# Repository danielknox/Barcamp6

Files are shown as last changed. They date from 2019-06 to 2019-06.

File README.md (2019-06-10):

# Barcamp6
Puzzle and Badges for Barcamp 6

Barcamp 6's theme was loosely based around the film The Fifth Element. Throughout the day a puzzle game played out for the 50+ attendees. In this repo are the files that made up the game. 

The badges, given to each attendee, are used to provide a clue to each tribe to locate their artefact and are used as part of the end sequence animation. They also fade their lights in/out approximately every 8 seconds (which looks quite cool when people are speaking/sitting in groups). 

The pcbs and puzzles took about two months to develop and produce. 

Special thanks to: 
Keith Greenhow (helped develop a number of the puzzles -- like the fourtime pad
Martin Falkner (for helping to assemble 40+ pcbs!)

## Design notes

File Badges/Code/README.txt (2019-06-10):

Needs the FastLED and IRLremote libraries. This can be compiled for attiny85 (production) or uno/leonardo (for debugging). 

I use https://raw.githubusercontent.com/damellis/attiny/ide-1.6.x-boards-manager/package_damellis_attiny_index.json. to compile for the ATtiny85 from the Arduino IDE:
- 8MHz internal clock.

HOWEVER! You need to modify the pins_arduino.h (appData/local/arduino15/packages/attiny/hardware/avr/1.0.2/variants/tiny8) to have the digitalPinToInterrupt macro.

Add this:
'#define digitalPinToInterrupt(p)  ((p) == 2 ? 0 : NOT_AN_INTERRUPT);

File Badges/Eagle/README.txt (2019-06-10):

Gerbers should contain the ready to go files, schematics contains the Eagle board files.

Fabrication:
I used SEEEDSTUDIO for board fabrication.

For production, Barcamp stencil was used with bi-directional engraving on laser cutter using OHP asertate. Laser outline was used to create a simple nested jig (0.1mm offset).
Use ducktape to secure acertate to jig and paste away!

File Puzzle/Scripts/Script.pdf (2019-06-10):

# Script

# Introduction

In the beginning there were four great tribes and they forged wondrous, magical artifacts: one of fire, one of water, one of earth and one of air.

The four seeked to expand their power and for centuries there was conflict.
Any peace was short lived.

As time moved on, the four became tired of war and an unsteady calm befell the land. Trade slowly grew and the four vied for power in other ways.

Fearful of what would happen if any nation was able to wield more than one artifact, they were hidden away and the locations of the artifacts (and how to use them) were gifted to a select few. But as with all things, this knowledge was slowly lost.

The artifacts are now little more than legend, but a great calamity is fortelled. Interest in the artifacts has grown and the other tribes covet their power once more. You have been tasked with uncovering the clues of our ancestors, recovering the artifacts and to wield them to stop our nation’s demise.

Attendees of Barcamp 6, you have until the end of the day to recover the lost artifact and the instructions on how to use them. At the end of the day we will gather together to perform the activation ritual to discover your fates.

# Altar Ceremony

1. “Can the four Stone Bearers come forth.”
2. Get upto four volunteers to bring their claimed stones to the front.
3. Repeat the following steps for each Stone, X, present:
a. Connect to the stone X’s BLE interface.
b. “Bearer of the X Stone; place the X Stone on the Altar”
c. Wait for the stone to be placed on the altar in its correct position.
d. “Please awaken the X Stone”
e. Once they reenact the relevant part of the Fifth Element end sequence
i. The wind blows
ii. | The fire burns
iii. | The rain falls
iv. | The ground stays
f. Set the X stone to mode 0x01.
g. “Now enter your activation sequence”
h. Wait for them to finish
i. Take note of Stone X’s final rotary position into victory calculator
j. “Please return from the altar”
4. After all present stones have been awakened and activated
5. Set the stones modes to the final states shown on the calculator (to show who betrayed whom).
6. Play badge outro shown on calculator.
7. Read out epilogues shown on calculator. (see below for narrative)

# Epilogues

## Failure cases

### For factions that failed to recover/activate their artifact

With the rise of the great calamity, your defenses fall; and your people scatter. You have died of dysentery.

### For factions that recover one artifact and selfishly activate

You wield the power of the artifact and your nation is invigorated and strengthened. Your people hold their own, but they (too) eventually succumb to the great calamity.

### For factions that claim multiple artifacts

You wield the power of (two/three/all four) artifacts and your nation is invigorated and strengthened beyond all previous measure. Your people fend of the great calamity and hold steadfast. But power lust grows in your capital and in a moment of weakness the great calamity takes the upper hand and strikes you people down.

## Success

You activate the four great artifacts and unite their power. With this unity, the calamity is averted, our leaders commit to working together and you witness the birth of a new age of greatness.

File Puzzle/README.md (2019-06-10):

# Barcamp Puzzles!

Barcamp 6 incorporated a puzzle game which played out throughout the day. Each attendee was assigned to a tribe (they were given an e-badge which flashed a team colour and had a coloured solder mask). The tribes had to recover an artifact of power and the information (scroll) to activate it. The clues available encouraged tribes to work individualistically (e.g. blaze vs terra), but each tribe would ultimately choose if they would activate the artifact for the benefit (?) of their tribe or for the benefit of all. Each tribe had a national newspaper and this was available from the newspaper stand during lunch - the newspaper contained a number of clues and backstory information.

A box (here-on called Pandora's Box) was placed in the main foyer during one of the talks. This box had a number of locks (key + combination). The box required much more working together between the tribes in order to remove all the locks. The box contained the writing "When you come, be prepared to share with barcampers. When you leave, be prepared to share it with the world." and the symbol for unity (each scroll had the symbol on it, as well as the other tribes symbols).

Listed below are the various puzzles that made up Barcamp 6.

## Artifact Locations
Each tribe's artifact was hidden in a different locations across campus. Each tribe's badge had a silkscreened clue on its rear revealing the location: Keynes duckpond (tribe flood),  Synapse-Soleil (tribe blaze), Wind-wall (tribe wind), Darwin's Primordial tree (tribe Terra).

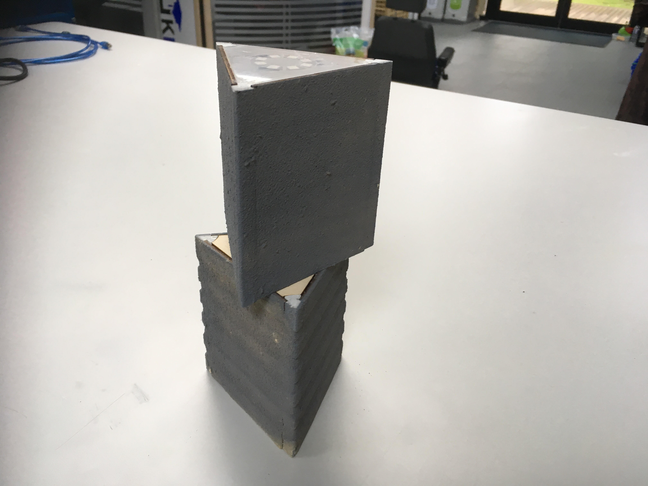
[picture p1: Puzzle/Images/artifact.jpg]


### Artifact Code
The artifacts have a ring of lights on their top, the lights can be in an on/off state creating different patterns; which in turn represent what tribe the artifact is 'aligned' too (a specific tribe or harmony). The position is ultimately used for determining what happens to everyone in the ending 'activation ceremony' (this was done in a huge staged lecture theatre with the lights dimmed low and attendees sitting in the stalls) - once the position is decided by each artifact bearer (person who last carried an artefact), we then use a IR remote to blast everyones badges to activate the appropiate ending light sequence.
The code for the stones can be found [here](https://os.mbed.com/users/Condo2k4/code/elemental_stone2/)

## Scroll locations

Each artifact's body was able to be rotated. As you rotated the body the top lights on the artifact changed to a different pattern. The pattern's were unique to each artifact to preventing copying and to stop people knowing immediately knowing a tribes final decision. The scrolls revealed the different patterns and what they represented. Each tribe had their own scroll and this was hidden in a geocache maze puzzle box. These were covered with sand and painted to give a concrete look. 
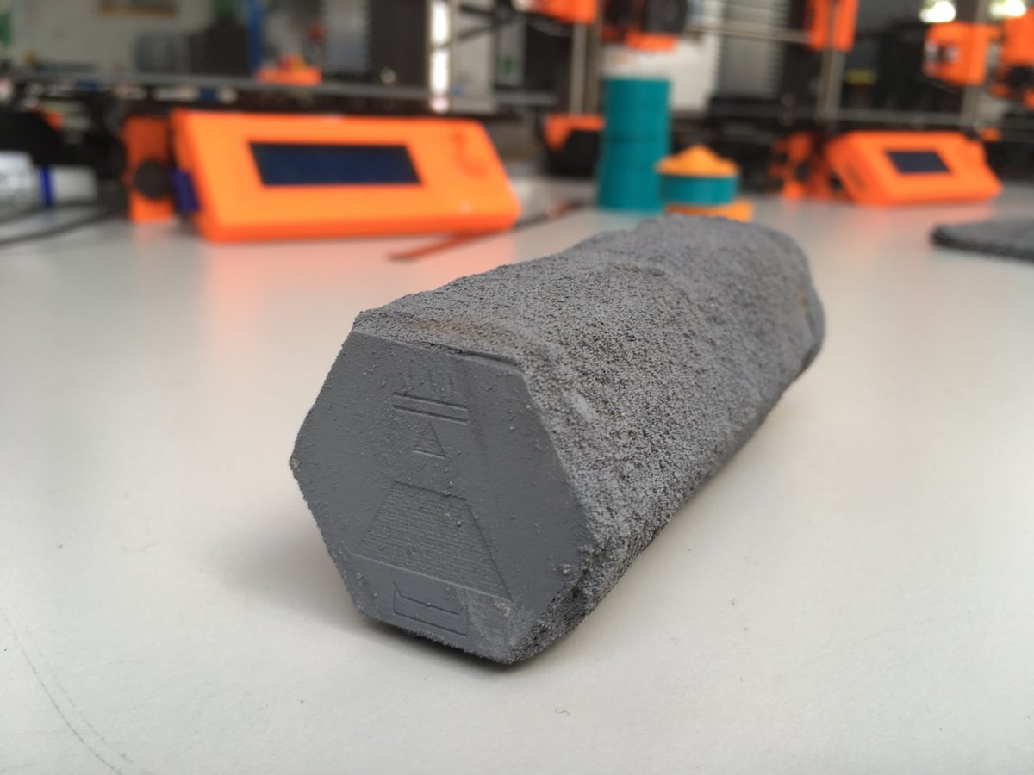
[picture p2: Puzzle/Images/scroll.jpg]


The scrolls were hidden near the artifact locations to limit the amount of walking required. The locations were:  Hymn (tribe flood),  Huella Humana (tribe blaze), Father Courage (tribe wind), Darwin Rose Garden (tribe Terra).

The location of the scrolls were revealed by placing a tribe specific card over a 'four time pad'. The text location clue would then be revealed by looking at the pad from a distance. The code for generating the four time pad (genetic algorithim!) can be found [here](https://github.com/condo2k4/MessageGrid)

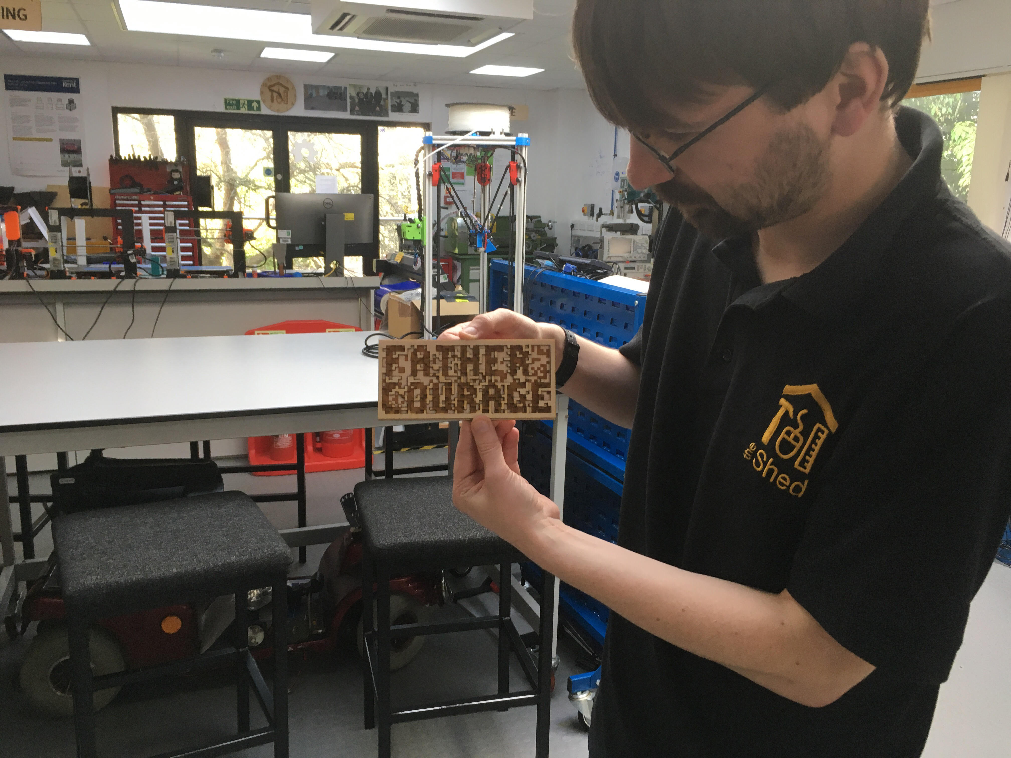
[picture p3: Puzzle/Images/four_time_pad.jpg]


Each tribe's newspaper also gave a clue to another tribes scroll location.  These clues were always in the same position on each paper and were incorporated into the article's title. E.g. "Hymn - Thousand singers join to celebrate anniversary of the Emperor's coronation", "Father Courage - Rev. heralded for bravery", etc.

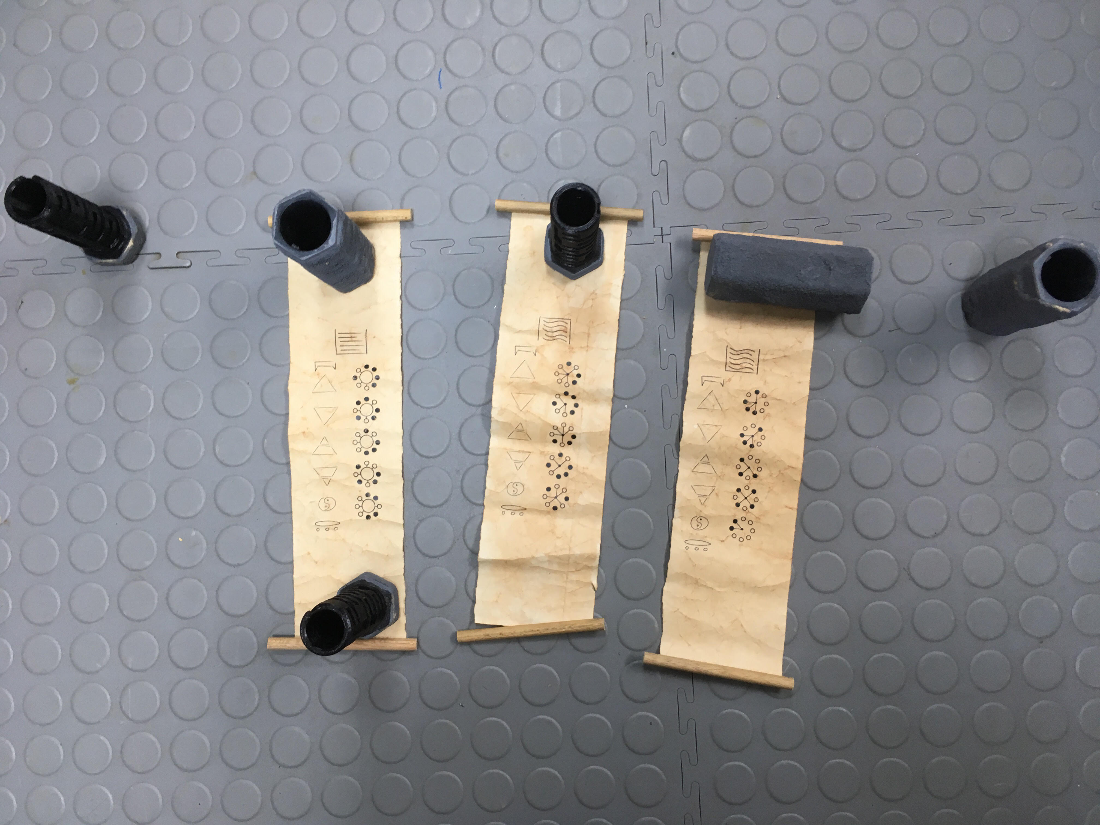
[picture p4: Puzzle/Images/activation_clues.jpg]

## Pandora's Box

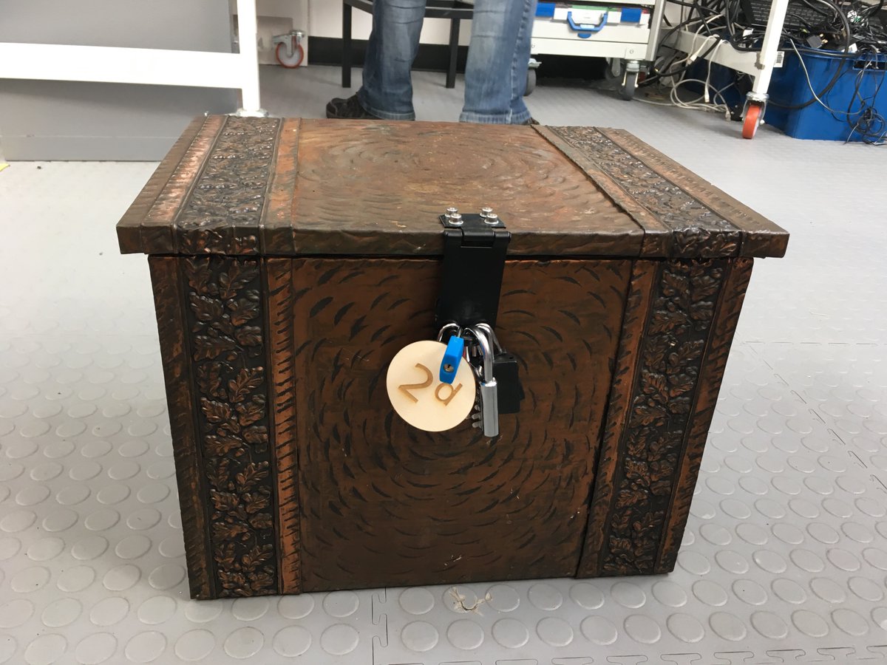
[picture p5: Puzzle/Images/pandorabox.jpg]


### Combination lock "2d"

Pandora's Box had a combination lock on it with a disc and engraving "2d". The combination lock had a 5 button code and it did not matter the order the code was entered in. The code was "23847". Each tribe's newspaper had a different price on it (e.g. "3d") and the engraving disk was the clue to use this information (and also gave one of the required numbers).

### Combination lock

Each tribe's room had a small piece of Banksy art. The art was always placed on the whiteboard corner nearest the presenter's desk. The art was related to each tribe's "darkside". On the reverse of the art was a greek symbol which represented the code position and roman numerals for the actual code.

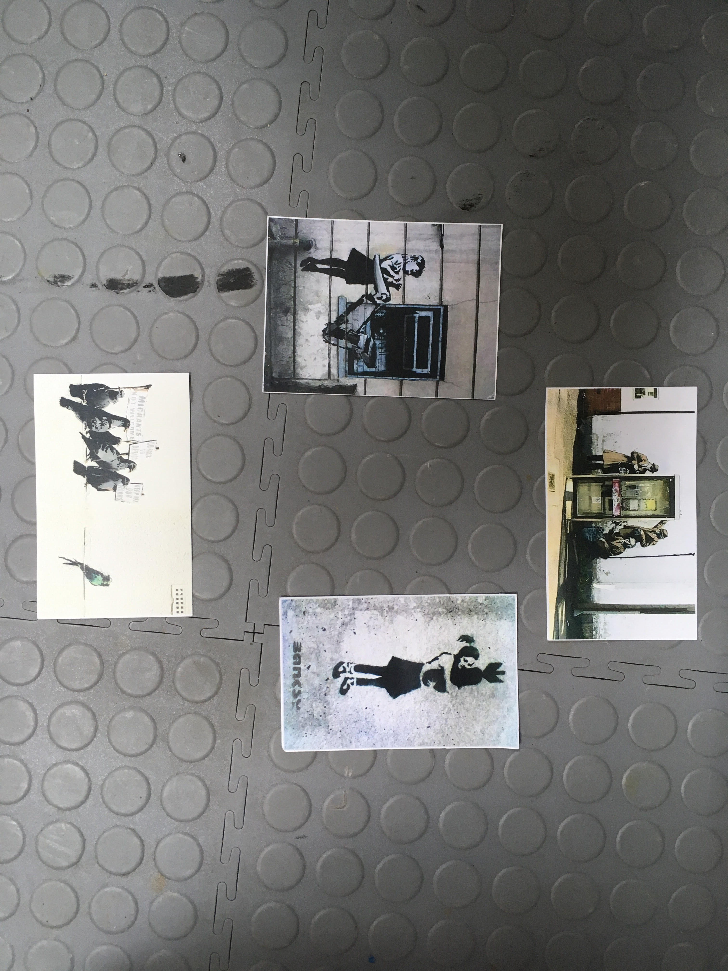
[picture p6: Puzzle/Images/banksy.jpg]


### Key lock

Because of an influx of late sign-ups we laser cut a set of badges using the badge outline file that I had prepared earlier for the event. Each badge had a unique character on it and position. When readout, it revealed a clue to the location of the key - "WOOLF_OUTSIDE_BINS". The key was hidden in a fake screw on one of the bins.

# The Message
Whilst the puzzle was to add a little bit of competitive and co-operative fun to Barcamp 6's lunch and time between talks, it also had central message - "That if we do not share our knowledge and wealth, we would ultimately be lead to our doom".

Essentially each tribe started working out for themselves and had their own national politics -- somewhat skewed to the extreme. The evidence of this was shown in each national newspaper --  the terra tribe was clearly totalitarian (1984 style references), blaze was expansionist, wind was xenophobic, and flood was focused on capitalistic gain. Whilst the overall theme of each newspaper incorporated the politics into it, the corner article on each paper clearly demonstrated this, e.g. "You won't be settled in Airia! -- with ministers taking a tough new stance on migrants to protect our jobs, resources and culture!". 

The bansky art in each room was also a mock to this state of affairs, for example, flood's was an image of a young girl being grabbed by a claw protruding from a cash machine ("money controls us"), blaze had an image of a girl hugging a nuke ("the horror of war next to the innocence and purity of the young girl – good and evil unified and questioned as to why we inherently indulge in war and fighting when peace can be all around us."), terra was surveillance officers listening to a phone booth ("the surveillance powers used/requested in the name of protecting us"), and wind's was a group of fat pigeons demanding a small African swallow stays away and keep's off their worms ("those that have so much readily turn away those with so little").

Upon opening Pandora's Box, beneath the slogan and unity symbol was stored a number of real-life pieces; intended to parody the story of each tribe into real life. Flood had a picture of a turtle whose shell had been deformed from a lifetime of being trapped in a piece of plastic ("we readily consume more than we need, without thinking the pain & suffering it can cause when we discard it"), blaze had a list of drone-strike kill counts which included civilian numbers ("war and fighting, regardless of its reasons, brings suffering to the innocent"), terra had a list of books that had been challenged/banned in the US in 2018 ("we fear what message materials might convey, and seek to hide it rather than to challenge?/discuss it"), and air had a photo of a young dead child being carried up a beach by a Turkish soldier, the child had died when their migrant boat had capsized whilst fleeing a war-zone ("Ultimately we are all people. But why do we readily turn our backs, despite having so much?"). 

The aim of the barcamp puzzle was to give the attendees the choice of taking things for themselves (and ultimately bring about their doom) or to choose to share their power with everyone else unconditionally (and bringing about a new age of greatness).

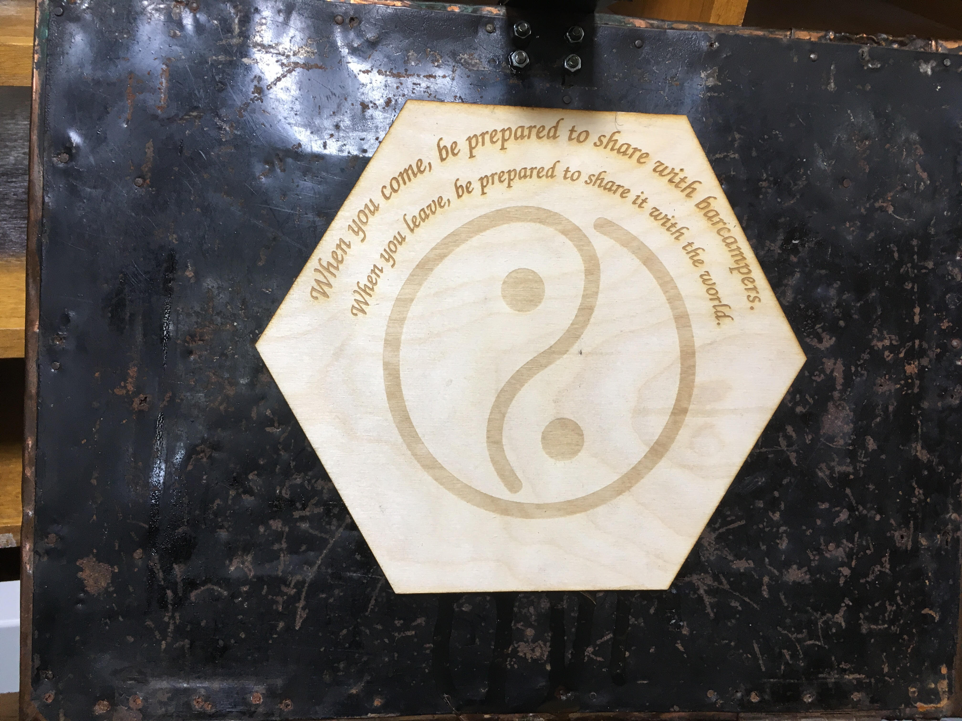
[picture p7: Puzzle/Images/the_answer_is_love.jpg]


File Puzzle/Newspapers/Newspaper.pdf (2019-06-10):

### Sunday, June 2

nd Est. 1984 | , 2019 | Price 3
d

# “Help Us! Please Help Us!”

## Radio call reveals horror of failed weapon test

The distress call confirms the extent of the
destruction caused by last week’s failed weapon test
with the death-toll now
estimated to have reached
12 million souls.

The call confirms previous speculation that a device
tested by the Blazian state went critical, causing
instant loss of life and
grave infrastructure
damage.

Despite multiple
offerings of assistance
by our nation’s leaders,
the Blazian state has
repeatedly denied the
weapon test and its
subsequent failure.

Diplomats plan to again
offer support at an
upcoming summit aimed
at defusing increasing
tensions between our
neighbouring allies.

## Blackouts expected

Following last week’s
devastation of the
Blazian state’s energy
production plants, our
officials again warn that
rolling blackouts are to
be expected. The
purpose of these
blackouts are intended to
maintain energy supply
for our nation’s
industrial production and
critical healthcare
services. Should citizens
be effected by these
blackouts and require
assistance, please
contact your local
representative of the
Ministry of Resource.

Authorised for distribution by the Democratic Terran Republic The Nation’s Only News!

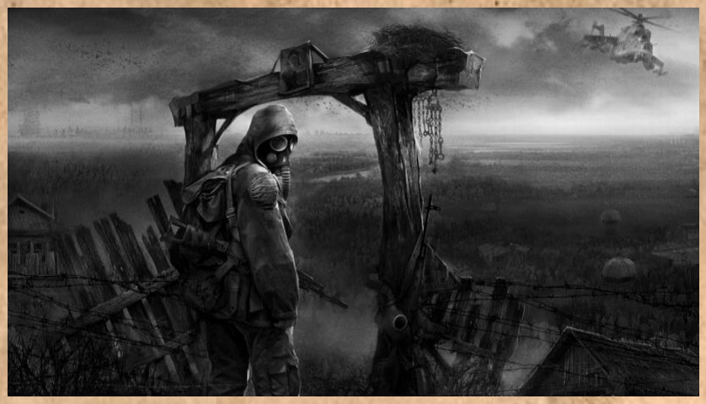
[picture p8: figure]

Artist’s depiction of the extent of devastation within Area 11

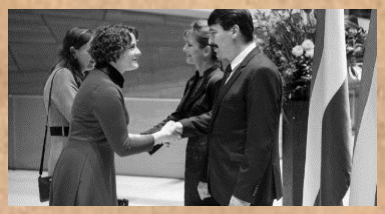
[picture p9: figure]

Emmunuel Goldstein
meets with Blazian state
ambassadors ahead of
submit to discuss potential aid

## Miss Humana Unveiled!

The pictures they don’t want you to see on page 3!

## New Book List Published!

Following an extensive review of all literature the Ministry of Truth has published their latest list of approved books. (page 10).

# The Daily Progress

### Monday, June 3

rd
, 2019 | Price 4
d

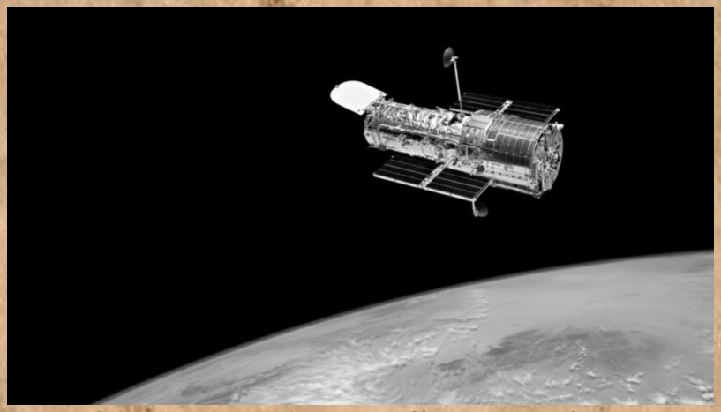
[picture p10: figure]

## Plough, min-till and no-till compared

Switching from
ploughing to min-till can
cut establishment costs,
but also increases the
risk of weed problems.

To help farmers identify
the best system for the
future, the Conservation
Agriculture and
Sustainable Farming
Practices project is
comparing a ploughbased system with min-till and low-till
approaches.

The three systems will
be assessed for their
riskiness, agronomy,
field operations,
productivity,
complexity, profitability
and sustainability.

## I-God

Come 2020, NSEA will
have a new eye tracking
the heavens and looking
to solve some of the
greatest scientific
mysteries we know of.

That’s thanks to a newly
approved mission, called
Spectral Imaging the
History of the Universe.
The instrument is
designed to tackle two
key questions: how life
evolved and how
common are some of the
crucial building blocks
of life?

“I’m really excited about
this new mission,”
NSEA administrator
Gwen Demarco said in a
statement.

### Life’s Always Greener on Our-Side

## The Rose Garden

Pictures from the grand opening of our nation’s latest national park on page 4!

## You Won’t be Settled in Airia!

Ministers take a tough new stance on migrants to protect our jobs, resources and culture! (page 10).

# The Daily Prophet

Eye of God – One telescope offers to transform astronomy, and us all

A major trial has been set up to find the most
profitable and sustainable way to grow arable crops
by comparing three
different establishment
systems over five years.

Establishment systems vary hugely from intensive soil cultivations such as
ploughing, through to
carrying out no cultivations at all with direct drilling.

Each approach has its pros and cons, making it
difficult to assess which is the best system.

### Tuesday, June 4

th, 2019 | Price 7
d

# SABOTAGE!

## Investigators reveal foreign interference with reactor

Investigators have
admitted for the first time that they believe the recent reactor meltdown in Area
11 was due to interference from a foreign power.

This confirmation is linked to the recent expulsion of Terran diplomats
following a series of
accusations and denials
from the highest levels of government.

Whilst the regional
office continues to
provide aid and
emergency supplies to
the area. Prime Minster
Schneizel has called a
meeting of the Nobels to
discuss further plans for
support and defence.

## Baron says now is the time to strike!

Baron Maximillian
Newcastle has again
vocally stated that he
believes the increasing
interference from foreign
powers is an opportunity
for expansion.

“We all know that the
Terran Republic have been
struggling to meet their
national energy needs and
has been suffering routinely from blackouts. This
tampering with one of our
reactors is just a way for them to fuel their own
propaganda machine.

Through our own inaction
we have allowed our
neighbour to inflict a barewound on our great nation. This latest move, by one of our neighbours, just reenforces that now is the
time to invade. Only
through struggle and
military conquest can we
evolve! ”

### Shining Light into the Darkest Corners!

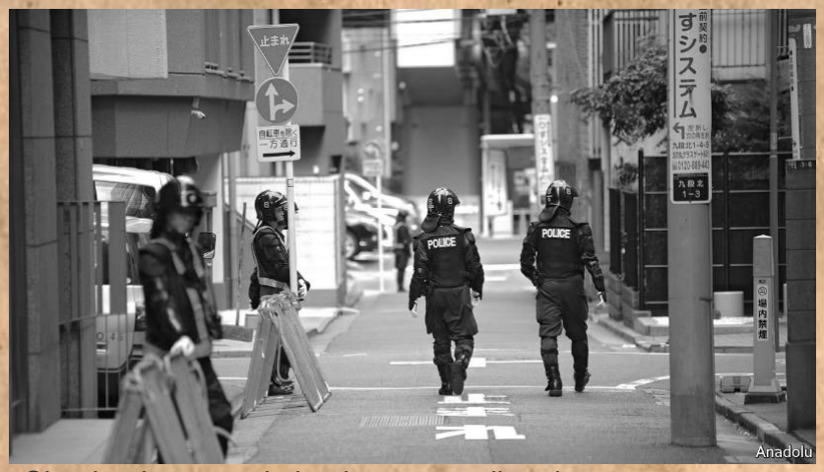
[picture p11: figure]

Checkpoints remain in place near all major state buildings

## Nuclear Attack?

Protect your family now! With a Lancer fiberglass blast & fallout shelter. (Page 10)

# The Daily Beacon

## Hymn

Thousand singers join to celebrate anniversary of the Emperor's coronation (page 5).

### Wednesday, June 5

th, 2019 | Price 8
d

# Market Turmoil Ahead!

## Aquarian companies face retaliation as trade war deepens

A top business lobby
group representing
Aquarian firms abroad
said they have “real
concerns” over how
international partners may respond to new Aquarian
trade tariffs.

This follows Pres. Thump
adding TalkFree to the
“entity list” curbing
Talkfree on its ability to do business in Aquaria.

These moves have
escalated existing trade
tensions between
Aquaria and its main
trading partners.

"Particularly in the wake
of the decision to put
TalkFree on the... entity
list, there are concerns
that the Terran Republic
may decide to retaliate
against Aquarian
companies," Mr Pinford
said.

"These are real concerns,
and they increase the
risk as people are
considering how they
should make
adjustments to their
business models," he
said.

His comments came as
the Aquarian Chambers
of Commerce (AqCham)
in Terra and Blazia
released a survey of its
members that found that
more than 40% had
relocated, or were
considering moving
production facilities,
because of new tariffs.

## Ready to talk

Diplomats from the
Terran Republic have
signalled willingness to
work with Aquaria to
solve their trade dispute. No discussions have
been scheduled since the
last round of talks ended
on the 10th May.

### The Bank Will Have its Due

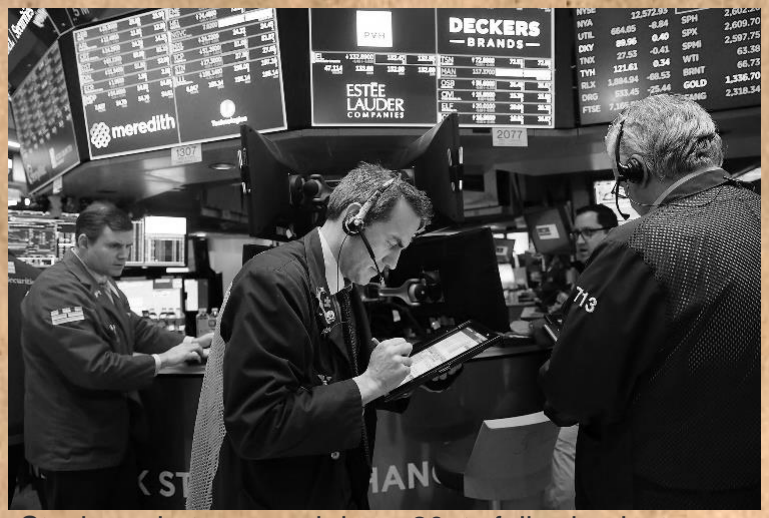
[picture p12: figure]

Stock markets opened down 20pts following last week’s ruling over TalkFree due to security concerns.

## Father Courage

Rev. heralded for bravery (page 6)

## Gold Mine!

Agreement to mine the poles for minerals offers prospectors treasure trove of possibilities! (page 10)

# The Daily Ledger

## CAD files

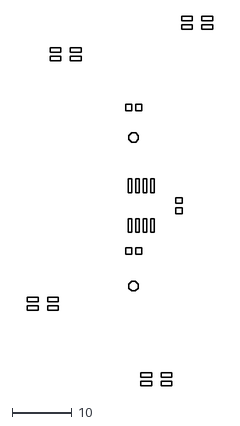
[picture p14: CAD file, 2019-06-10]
Badges/Eagle/barcamp_stencil.dxf
31.1 x 62.1

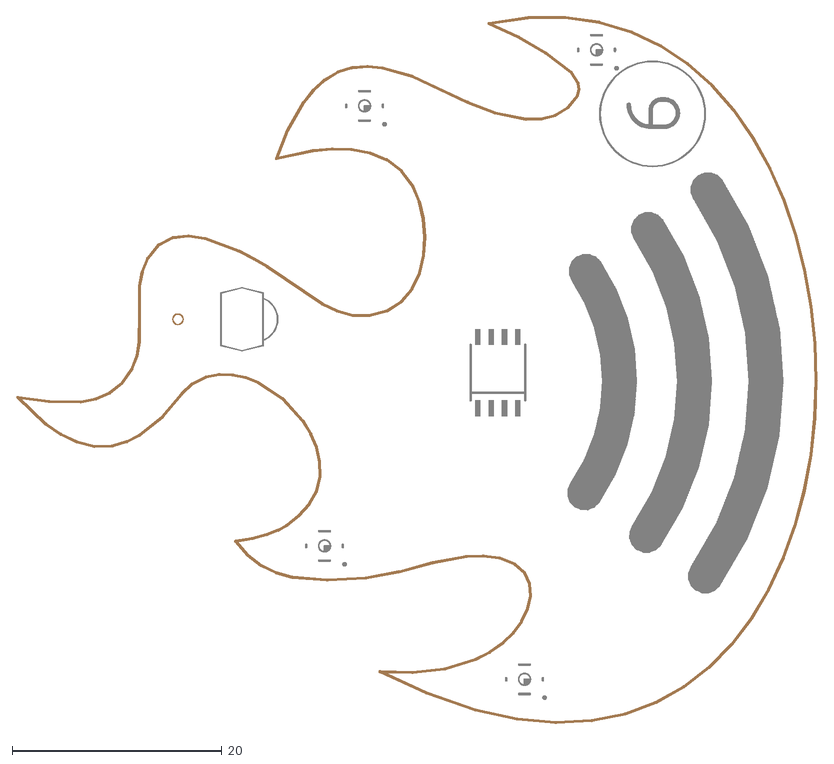
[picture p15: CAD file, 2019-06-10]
Badges/Eagle/barcamp_laser_outline.dxf
76.3 x 67.4

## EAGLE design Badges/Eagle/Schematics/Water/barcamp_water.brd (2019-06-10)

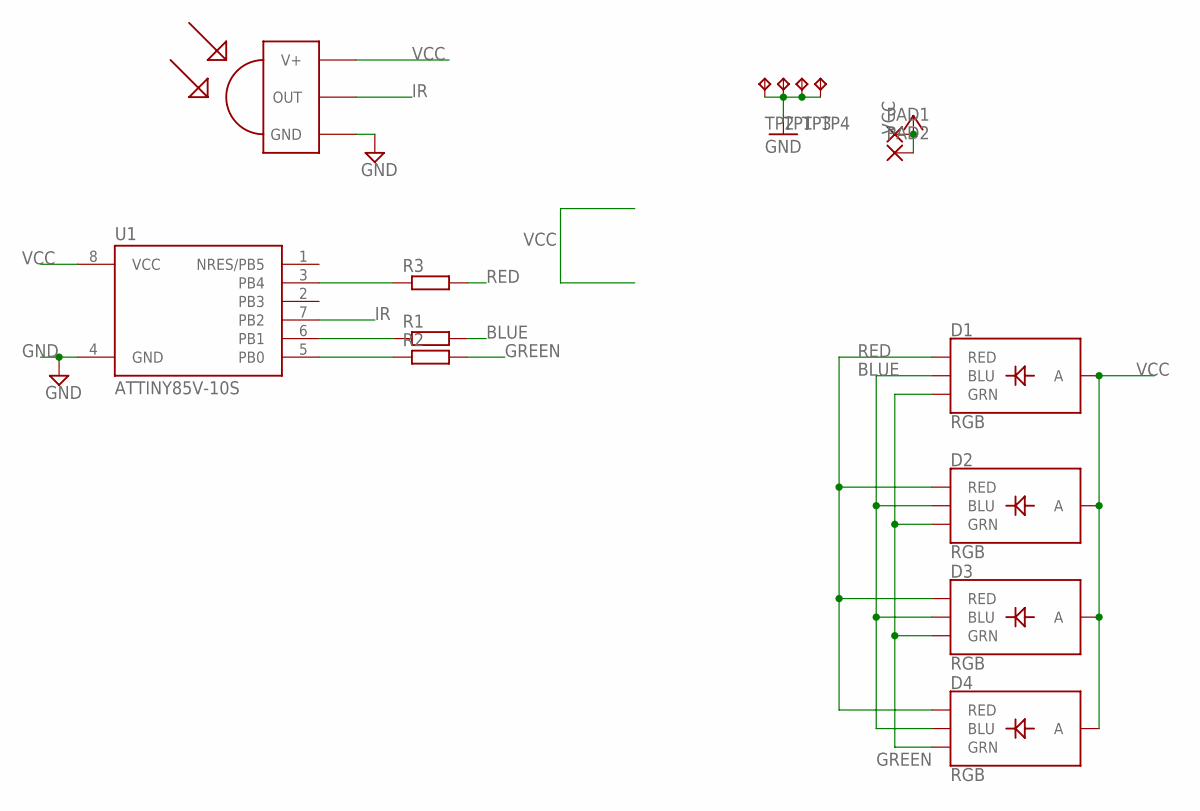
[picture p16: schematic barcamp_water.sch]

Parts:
D1, D2, D3, D4: RGB; P-LCC-4-3
PAD1, PAD2: 3,17/1,3
R1, R2: 12ohm; R0603
R3: R-EU_R0603; R0603
TP1, TP2, TP3, TP4: TPTP20SQ; TP20SQ
U1: ATTINY85V-10S; SOIC8_EIAJ_208MIL
U$1: TSOP4838; TSOP18XX

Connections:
BLUE: D1.3 (BLU), D2.3 (BLU), D3.3 (BLU), D4.3 (BLU), R1.2
GND: TP1.TP, TP2.TP, TP3.TP, TP4.TP, U1.4 (GND), U$1.GND
GREEN: D1.2 (GRN), D2.2 (GRN), D3.2 (GRN), D4.2 (GRN), R2.2
IR: U1.7 (PB2), U$1.OUT
unnamed: R1.1, U1.6 (PB1)
unnamed: R2.1, U1.5 (PB0)
unnamed: R3.1, U1.3 (PB4)
RED: D1.1 (RED), D2.1 (RED), D3.1 (RED), D4.1 (RED), R3.2
VCC: D1.4 (A), D2.4 (A), D3.4 (A), D4.4 (A), PAD1.1, PAD2.1, U1.8 (VCC), U$1.VCC (V+)

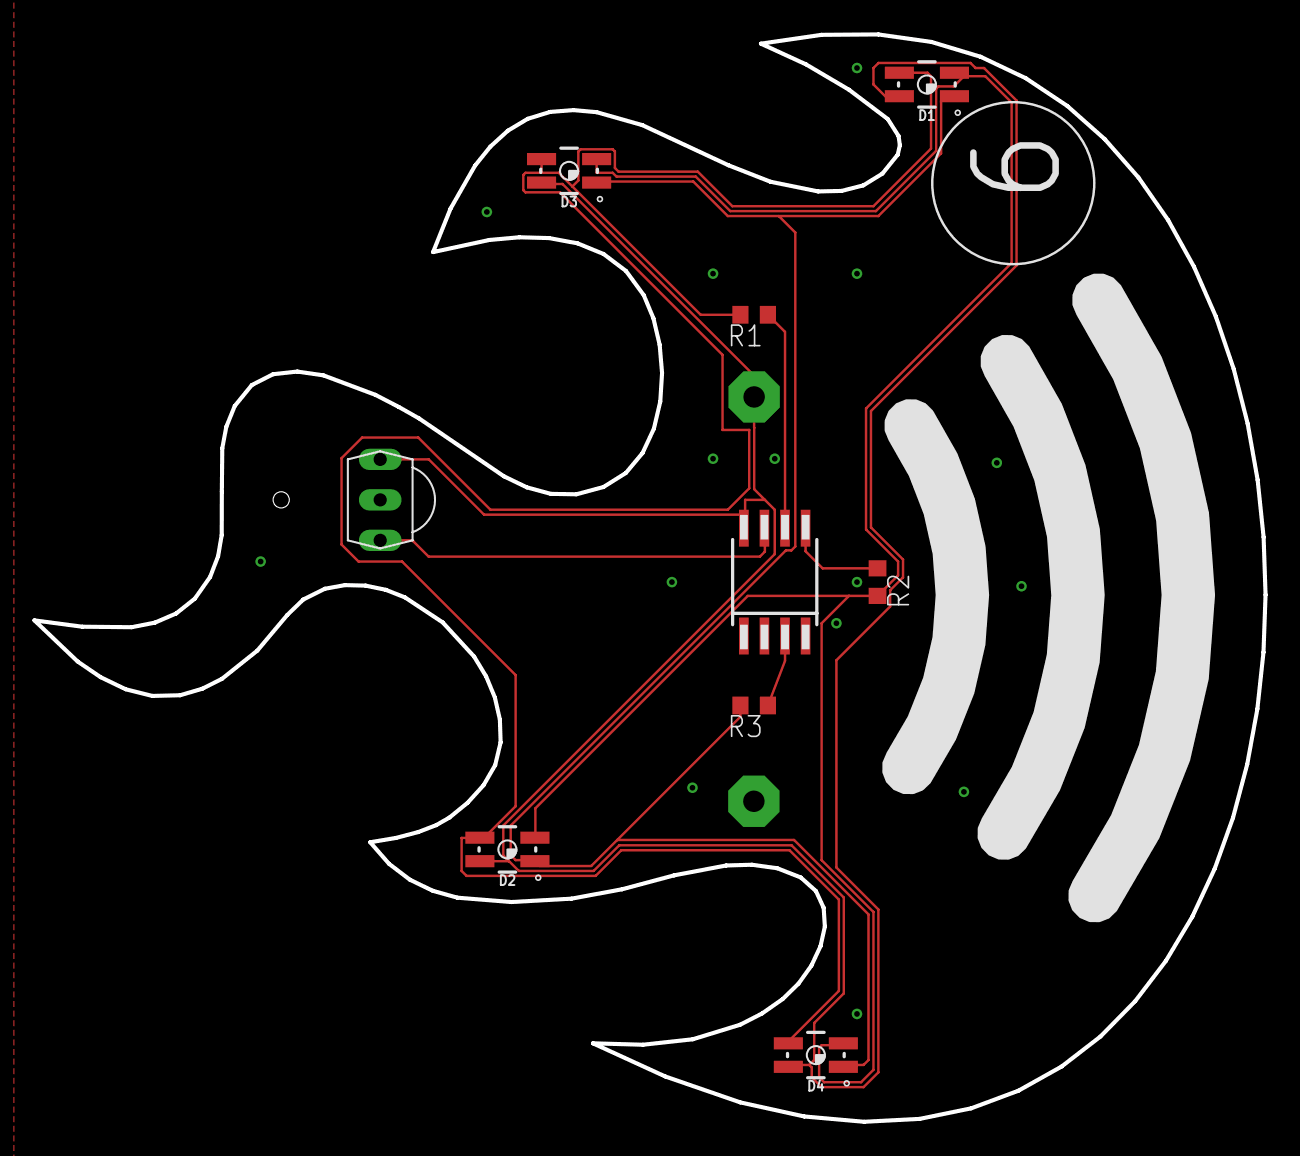
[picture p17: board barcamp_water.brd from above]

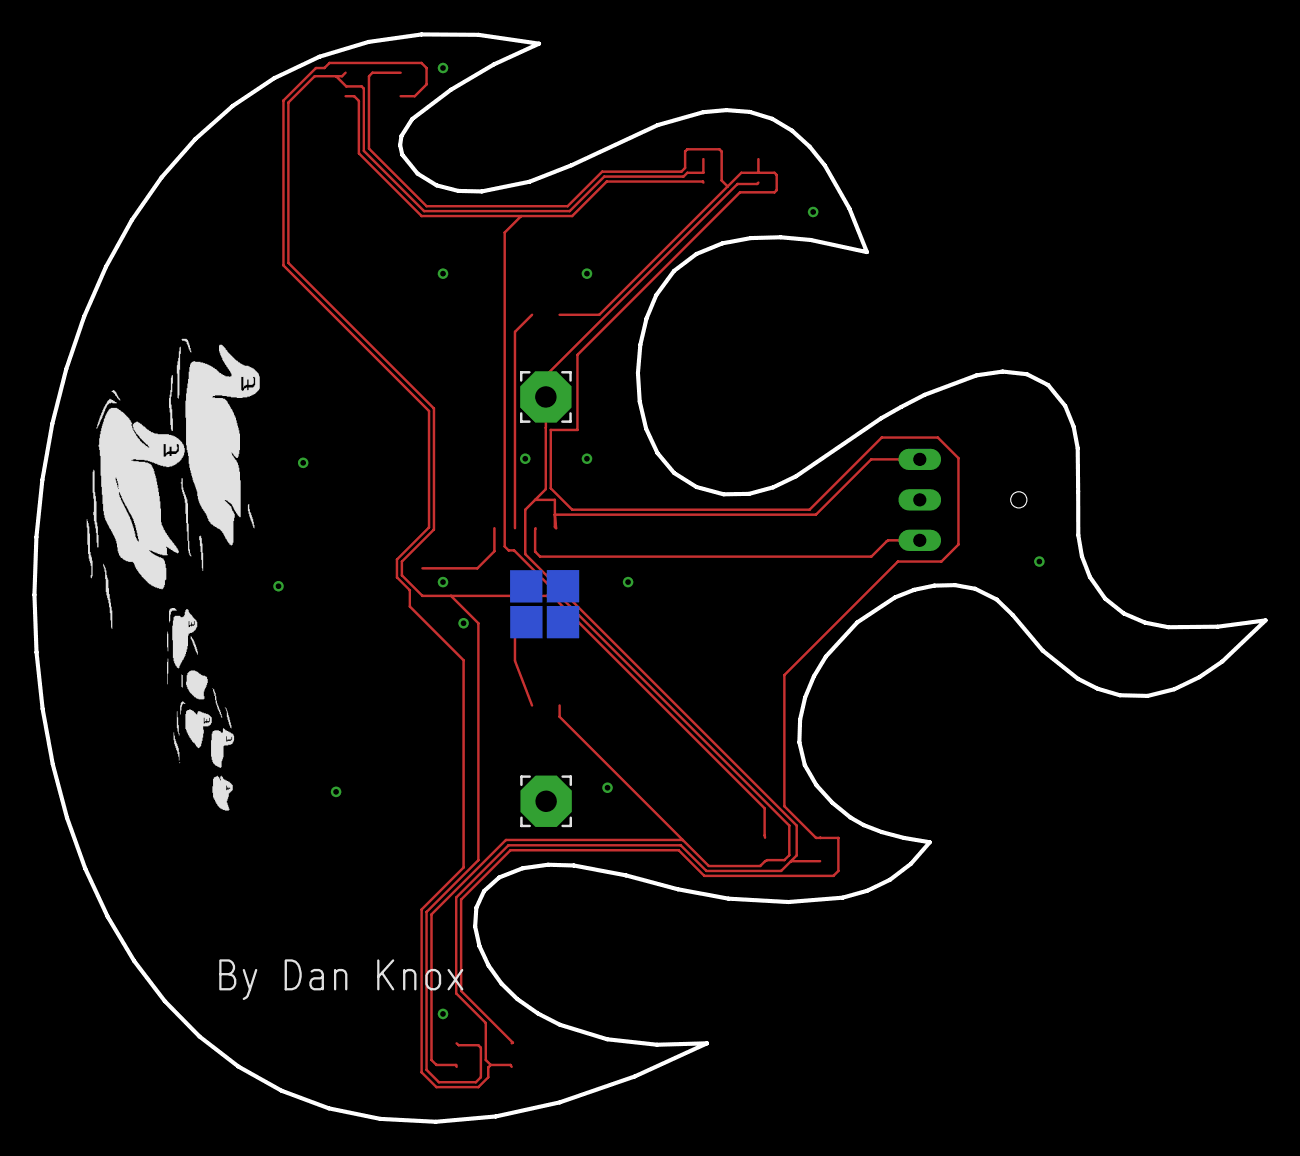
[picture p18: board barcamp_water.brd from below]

Board: 2 copper layers, 76.0 x 67.2 mm, 15 parts (6 on the bottom side), 9 nets.

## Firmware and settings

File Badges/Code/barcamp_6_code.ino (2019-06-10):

#include <FastLED.h>

#include "IRLremote.h"

#include <avr/sleep.h>

#include <avr/power.h>

#include <avr/interrupt.h>

#include <avr/wdt.h>

#include <EEPROM.h>

#define DEBUG
#define RED_PIN 4
#define GREEN_PIN 0
#define BLUE_PIN 1
#define IR_PIN 2

#define BEER_COUNT_DEFAULT 2
#define TEAM_DEFAULT neutral

#define FIRST_RUN_ADDR        (0)
typedef byte FIRST_RUN_TYPE;
#define LOCAL_SETTINGS_ADDR   (FIRST_RUN_ADDR + sizeof(FIRST_RUN_TYPE))

#define adc_disable()(ADCSRA &= ~(1 << ADEN)) // macro to disable ADC

#if defined(ARDUINO_AVR_UNO) || defined(ARDUINO_AVR_LEONARDO)
#warning "Debug statements will be enabled"
#elif defined(ARDUINO_attiny) || defined(ARDUINO_AVR_DIGISPARK)
#warning "Production Mode"
#else
#error "Unsupported board type"
#endif

enum wake {
  def = 0, ir = 1, dog = 2
}; // enum for types of wake

enum teamColour : byte {
  fire = 0, earth = 90,  air = 159, water = 160, neutral = 42
}; // enum for team colours

CRGBPalette16 teamPallet(
  CHSV( (teamColour) fire, 255, 255),
  CHSV( (teamColour) fire, 255, 255),
  CHSV( (teamColour) fire, 255, 255),
  CHSV( (teamColour) fire, 255, 255),
  CHSV( (teamColour) water, 255, 255),
  CHSV( (teamColour) water, 255, 255),
  CHSV( (teamColour) water, 255, 255),
  CHSV( (teamColour) water, 255, 255),
  CHSV( (teamColour) earth, 255, 255),
  CHSV( (teamColour) earth, 255, 255),
  CHSV( (teamColour) earth, 255, 255),
  CHSV( (teamColour) earth, 255, 255),
  CHSV( (teamColour) air, 200, 255),
  CHSV( (teamColour) air, 200, 255),
  CHSV( (teamColour) air, 200, 255),
  CHSV( (teamColour) air, 200, 255)
);

enum irCodes : uint32_t
{
  changeTeamToFire = 4033872000,
  changeTeamToEarth = 4050714752,
  changeTeamToWater = 4084400256,
  changeTeamToAir = 4067557504,
  changeTeamToNeutral = 2989621376,
  playVictoryAnimation = 3377004672,
  playFailAnimationFireDominant = 3461218432,
  playFailAnimationWaterDominant = 3478061184,
  playFailAnimationEarthDominant = 3410690176,
  playFailAnimationAirDominant = 3393847424,
  playFailAnimationNeutralDominant = 479529344,
  playRegret = 1423179904,
  flashNumOfBeers = 3107520640,
  incrementNumOfBeers = 2686451840,
  decrementNumOfBeers = 2703294592,
  resurrect = 3073835136,
  kill = 1406337152
}; // enum for translating IR commands to game events

struct settings {
  volatile teamColour currentTeam = TEAM_DEFAULT;
  volatile byte beerCount = BEER_COUNT_DEFAULT;
  volatile boolean dead = false;
} localSettings;

CPanasonic IRLremote; // shitty ir remote uses Nec protocol

volatile wake wake_source = def; // allows us to handle different wakeup sources

ISR(WDT_vect) {
  wdt_disable(); // disable watchdog
  pinChangeInteruptDisable(); // disable pinchange
  sleep_disable(); // disable sleep
  wake_source = dog; // change wake source to dog
}

ISR(PCINT0_vect) {
  wdt_disable(); // disable watchdog
  pinChangeInteruptDisable(); // disable pinchange
  sleep_disable(); // disable sleep
  wake_source = ir; // change wake source to ir
}

/**
    Enable watchdog timer
*/
void watchdogEnable() {
#if defined(ARDUINO_attiny) || defined(ARDUINO_AVR_DIGISPARK)
  WDTCR = bit(WDCE) | bit(WDE); // allow changes to wdt, disable reset
  WDTCR = bit(WDIE) | bit(WDP3) | bit(WDP0); // set wdt to interupt mode, with 8 seconds delay
#endif
#if defined(ARDUINO_AVR_UNO) || defined (ARDUINO_AVR_LEONARDO)
  WDTCSR = bit (WDCE) | bit (WDE); // allow changes to wdt, disable reset
  WDTCSR = bit (WDIE) | bit (WDP3) | bit (WDP0); // set wdt to interupt mode, with 8 seconds delay
#endif
  wdt_reset(); // kick the dog
}

/**
    Enable pinchangeinterupt
*/
void pinChangeInteruptEnable() {
#if defined(ARDUINO_attiny) || defined(ARDUINO_AVR_DIGISPARK)
  GIMSK |= (1 << PCIE); // pin change interrupt enable
  PCMSK |= (1 << PCINT2); // pin change interrupt enabled for PCINT2
#endif
#if defined(ARDUINO_AVR_UNO) || defined (ARDUINO_AVR_LEONARDO)
  PCMSK0 |= (1 << PCINT2); // pin change interrupt enable for PCINT2
  PCIFR = 0x1; // pin change interrupt flag
#endif
}

/**
    Disable pinchangeinterupt
*/
void pinChangeInteruptDisable() {
#if defined(ARDUINO_AVR_UNO) || defined (ARDUINO_AVR_LEONARDO)
  PCMSK0 |= (0 << PCINT2); // pin change interrupt disable for PCINT2
  PCIFR = 0x0; // pin change interrupt flag
#endif
#if defined(ARDUINO_attiny) || defined(ARDUINO_AVR_DIGISPARK)
  GIMSK |= (0 << PCIE); // pin change interrupt disable
  PCMSK |= (0 << PCINT2); // pin change interrupt disable for PCINT2
#endif
}

/**
    Handles putting the board to sleep with two wakeup sources, IR and watchdog timer
*/
void enterSleep() {
  showAnalogRGB(CRGB::Black); // turns off leds
  MCUSR = 0; // clear "reset" flags
  cli(); // disable interupts
  watchdogEnable();
  pinChangeInteruptEnable();
  sleep_enable(); // enable sleep
  sei(); // enable interupts
  sleep_cpu(); // actually sleep the cpu
}

/**
    On first run, default populate the eeeprom
*/
boolean firstRun() {
  FIRST_RUN_TYPE i;
  EEPROM.get(FIRST_RUN_ADDR, i);
  if (i != 1) {
#if defined(ARDUINO_AVR_UNO) || defined (ARDUINO_AVR_LEONARDO)
    Serial.println("First Run");
#endif
    EEPROM.put(LOCAL_SETTINGS_ADDR, localSettings);
    EEPROM.put(FIRST_RUN_ADDR, 1);
    return true;
  }
  return false;
}

/**
    Loads the settings from eeprom
*/
void loadSettings() {
  EEPROM.get(LOCAL_SETTINGS_ADDR, localSettings);
#if defined(ARDUINO_AVR_UNO) || defined (ARDUINO_AVR_LEONARDO)
  Serial.println("Loaded Settings");
#endif
}

/**
    Updates the eeprom settings
*/
void updateSettings() {
  EEPROM.put(LOCAL_SETTINGS_ADDR, localSettings);
#if defined(ARDUINO_AVR_UNO) || defined (ARDUINO_AVR_LEONARDO)
  Serial.println("Updated Settings");
#endif
}

/**
    Switch team
*/
void switchTeam(teamColour newTeam) {
  if (localSettings.currentTeam != newTeam) {
    localSettings.currentTeam = newTeam;
#if defined(ARDUINO_AVR_UNO) || defined (ARDUINO_AVR_LEONARDO)
    Serial.print("Team Switched: ");
    Serial.println(localSettings.currentTeam, HEX);
#endif
    updateSettings();
    flashTeam();
  }
}

void setDeath(boolean dead) {
  localSettings.dead = dead;
  updateSettings();
}

/**
    Pass a RGB structure and create it using each LED channel
*/
void showAnalogRGB(const CRGB & rgb) {
  // Common anode LED, so need to subtract
  analogWrite(RED_PIN, 255 - rgb.r / 8);
  analogWrite(GREEN_PIN, 255 - rgb.g / 6);
  analogWrite(BLUE_PIN, 255 - rgb.b);
}

/**
    Set LEDs to team colour at given brightness
*/
void showTeamColour(byte brightness) {
  if (localSettings.currentTeam == (teamColour) air) {
    showAnalogRGB( CHSV( localSettings.currentTeam, 200, brightness )); // desaturate air so it looks closer to white
  } else {
    showAnalogRGB( CHSV( localSettings.currentTeam, 255, brightness ));
  }
}

/**
    Flicker effect
*/
void flicker(int duration) {
  while (duration > 200) {
    showTeamColour(30 + random(225));
    int r = random(200);
    delay(r);
    duration -= r;
  }
  showTeamColour(30 + random(225));
  delay(duration);
}

/**
    Cycles through all team colours in a nice blend
*/
void neutralCycle() {
  for (byte j = 0; j < 255; j++) {
    showAnalogRGB((ColorFromPalette( teamPallet, j)));
    delay(50);
  }
}

/**
    Loosing animation -- flicker period gradually increases over 'stable' period until death.
*/
#define CYCLE_STEP_MS     (100)
#define CYCLE_STEP_DURATION_MS  (1100)

//Total duration = ( CYCLE_STEP_DURATION_MS * CYCLE_STEP_DURATION_MS ) / CYCLE_STEP_MS

void loose(teamColour dominantColour) {
  showTeamColour(255);
  if (dominantColour == localSettings.currentTeam) // dominant team gets to live (only a little bit longer!!)
    delay(20000);
  else {
    delay(5000);
  }
  int timer = CYCLE_STEP_DURATION_MS;

  while (timer > 0) {
    showTeamColour(255);
    delay(timer);
    flicker(CYCLE_STEP_DURATION_MS - timer);
    timer -= CYCLE_STEP_MS;
  }
  showAnalogRGB(CRGB::Black);
  setDeath(true);
}

void victory(byte regret) {
  if (regret == 0) { // regret means we already went through the loose scene and everyone wants to 'undo' their actions
    loose((teamColour) neutral); // make it look like we lost
  }
  // A dim white light (a ray of hope type shit)
  setDeath(false);
  CRGB ghost = CRGB::GhostWhite;
  showAnalogRGB(ghost.fadeToBlackBy(253));
  delay(10000);


  // Gradually increase brightness -- not quite sure why the transition to this is choppy
  for (byte i = 253; i > 0; i--) {
    CRGB white = CRGB::GhostWhite;
    showAnalogRGB(white.fadeToBlackBy(i));
    delay(50);

  }

  delay(5000);

  // Shift to first colour in pallet
  for (byte i = 0; i < 255; i++) {
    showAnalogRGB(blend(CRGB::GhostWhite, ColorFromPalette( teamPallet, 0), i));
    delay(10);
  }

  // Begin cycling through the team colour pallet
  neutralCycle();

  // Rainbow mix -- because everyone deserves more awesome
  CRGBPalette16 myPalette = RainbowStripeColors_p;

  // Shift to the more awesome mix
  for (byte i = 0; i < 255; i++) {
    showAnalogRGB(blend(ColorFromPalette( teamPallet, 255), ColorFromPalette( myPalette, 0), i));
    delay(10);
  }

  byte numOfCycles = 0;
  while (numOfCycles < 10) {
    // Cycle through the awesome mix
    for (byte i = 0; i < 255; i++) {
      showAnalogRGB(ColorFromPalette( myPalette, i));
      delay(50);
    }
    numOfCycles++;
  }

  //  Player becomes neutral
  switchTeam((teamColour) neutral);
}

/**
    Simple fade in and out of team colour
*/
void heartbeat() {
#if defined(ARDUINO_AVR_UNO) || defined (ARDUINO_AVR_LEONARDO)
  Serial.println("Heartbeat");
#endif
  if (localSettings.dead == false) {
    if (localSettings.currentTeam == (teamColour) neutral) {
      neutralCycle();
    }
    else {
      for (byte i = 0; i < 255; i++) {
        showTeamColour(i);
        delay(2);
      }
      for (byte i = 255; i > 0; i--) {
        showTeamColour(i);
        delay(2);
      }
    }
  }
}

/**
    Cycle through team colours. Good for testing channels
*/
void colorBars() {
  showAnalogRGB(CRGB::Red);
  delay(500);
  showAnalogRGB(CRGB::Green);
  delay(500);
  showAnalogRGB(CRGB::Blue);
  delay(500);
  showAnalogRGB( CHSV( (teamColour) air, 200, 255) );
  delay(500);
}

/**
    Flashes your team
*/
void flashTeam() {
#if defined(ARDUINO_AVR_UNO) || defined (ARDUINO_AVR_LEONARDO)
  Serial.println("Team Flash");
#endif
  if (localSettings.currentTeam == (teamColour) neutral) {
    colorBars();
  } else {
    for (byte i = 0; i < 2; i++) {
      showAnalogRGB(CRGB::Black);
      delay(500);
      showTeamColour(255);
      delay(500);
    }
  }
}

/**
    Increment beer allowance
*/
void incrementBeer() {
  if (localSettings.beerCount < 255) {
    localSettings.beerCount++;
    updateSettings();
  }
}

/**
    Decrement beer allowance
*/
void decrementBeer() {
  if (localSettings.beerCount > 0) {
    localSettings.beerCount--;
    updateSettings();
  }
}

/**
    Flashes your beer allowance
*/
void flashBeerCount() {
#if defined(ARDUINO_AVR_UNO) || defined (ARDUINO_AVR_LEONARDO)
  Serial.println("Beer Flash");
#endif
  for (byte i = 0; i < localSettings.beerCount; i++) {
    showAnalogRGB(CRGB::Black);
    delay(500);
    showAnalogRGB(CRGB::White);
    delay(500);
  }
}

void handleIr() {
  auto data = IRLremote.read(); // this contains the IR data

#if defined(ARDUINO_AVR_UNO) || defined (ARDUINO_AVR_LEONARDO)
  Serial.println("Handling IR");
#endif
  if (data.address == 0x2002) {
    switch (data.command) { // the command that was sent

      case (irCodes) changeTeamToFire:
        #if defined(ARDUINO_AVR_UNO) || defined (ARDUINO_AVR_LEONARDO)
          Serial.println("Change team fire");
        #endif
        switchTeam((teamColour) fire);
        break;
      case (irCodes) changeTeamToEarth:
        #if defined(ARDUINO_AVR_UNO) || defined (ARDUINO_AVR_LEONARDO)
          Serial.println("Change team earth");
        #endif
        switchTeam((teamColour) earth);
        break;
      case (irCodes) changeTeamToWater:
        #if defined(ARDUINO_AVR_UNO) || defined (ARDUINO_AVR_LEONARDO)
          Serial.println("Change team water");
        #endif
        switchTeam((teamColour) water);
        break;
      case (irCodes) changeTeamToAir:
        #if defined(ARDUINO_AVR_UNO) || defined (ARDUINO_AVR_LEONARDO)
          Serial.println("Change team air");
        #endif
        switchTeam((teamColour) air);
        break;
      case (irCodes) changeTeamToNeutral:
        #if defined(ARDUINO_AVR_UNO) || defined (ARDUINO_AVR_LEONARDO)
          Serial.println("Change team neutral");
        #endif
        switchTeam((teamColour) neutral);
        break;

      case (irCodes) playVictoryAnimation:
        #if defined(ARDUINO_AVR_UNO) || defined (ARDUINO_AVR_LEONARDO)
          Serial.println("Play victory");
        #endif
        victory(0);
        break;
      case (irCodes) playRegret:
        #if defined(ARDUINO_AVR_UNO) || defined (ARDUINO_AVR_LEONARDO)
          Serial.println("Play Regret");
        #endif
        victory(1);
        break;

      case (irCodes) resurrect:
        #if defined(ARDUINO_AVR_UNO) || defined (ARDUINO_AVR_LEONARDO)
          Serial.println("Resurrect");
        #endif
        setDeath(false);
        break;

      case (irCodes) kill:
        #if defined(ARDUINO_AVR_UNO) || defined (ARDUINO_AVR_LEONARDO)
          Serial.println("Killed Player");
        #endif
        setDeath(true);
        break;
        
      case (irCodes) playFailAnimationFireDominant:
        #if defined(ARDUINO_AVR_UNO) || defined (ARDUINO_AVR_LEONARDO)
          Serial.println("Fire dominant");
        #endif
        loose((teamColour) fire);
        break;
      case (irCodes) playFailAnimationWaterDominant:
        #if defined(ARDUINO_AVR_UNO) || defined (ARDUINO_AVR_LEONARDO)
          Serial.println("Water dominant");
        #endif
        loose((teamColour) water);
        break;
      case (irCodes) playFailAnimationEarthDominant:
        #if defined(ARDUINO_AVR_UNO) || defined (ARDUINO_AVR_LEONARDO)
          Serial.println("Earth dominant");
        #endif
        loose((teamColour) earth);
        break;
      case (irCodes) playFailAnimationAirDominant:
        #if defined(ARDUINO_AVR_UNO) || defined (ARDUINO_AVR_LEONARDO)
          Serial.println("Air dominant");
        #endif
        loose((teamColour) air);
        break;
      case (irCodes) playFailAnimationNeutralDominant:
        #if defined(ARDUINO_AVR_UNO) || defined (ARDUINO_AVR_LEONARDO)
          Serial.println("Neutral dominant");
        #endif
        loose((teamColour) neutral);
       break;

      case (irCodes) flashNumOfBeers:
        #if defined(ARDUINO_AVR_UNO) || defined (ARDUINO_AVR_LEONARDO)
          Serial.println("Flash beer count");
        #endif
        flashBeerCount();
        break;

      case (irCodes) incrementNumOfBeers:
        #if defined(ARDUINO_AVR_UNO) || defined (ARDUINO_AVR_LEONARDO)
          Serial.println("Increment number of beers");
        #endif
        incrementBeer();
        flashBeerCount();
        break;

      case (irCodes) decrementNumOfBeers:
        #if defined(ARDUINO_AVR_UNO) || defined (ARDUINO_AVR_LEONARDO)
          Serial.println("Decrement number of beers");
        #endif
        decrementBeer();
        flashBeerCount();
        break;

      default:
#if defined(ARDUINO_AVR_UNO) || defined (ARDUINO_AVR_LEONARDO)
        Serial.print("Unknown IR: ");
        Serial.println(data.command);
#endif
        break;
    }
  } else {
#if defined(ARDUINO_AVR_UNO) || defined (ARDUINO_AVR_LEONARDO)
    Serial.println("For your reference:");
    Serial.print("0x");
    Serial.println(data.address, HEX);
    Serial.println(data.command);
#endif
  }
}

void loop() {
#if defined(ARDUINO_AVR_UNO) || defined (ARDUINO_AVR_LEONARDO)
  wake_source = ir; // needed to trap leonardo into a constant ir loop for testing
#endif

  switch (wake_source) {
    case dog:
      {
        heartbeat();  // call color bars
        wake_source = def;  // reset wake_source
        break;
      }
    case ir:
      {
        unsigned long startMillis = millis();
        // Window to recieve IR
        while (IRLremote.receiving() || ( (unsigned long)(millis() - startMillis) <= 2000)) {
          if (IRLremote.available())  // we have some ir data
          {
            handleIr();
            break;
          }
        }
        wake_source = def; // reset wake_source
        break;
      }
    default:
      {
        break;
      }
  }
#if defined(ARDUINO_attiny)
  enterSleep(); // power down cpu if atiny
#endif
}

void setup() {
#if defined(ARDUINO_AVR_UNO) || defined (ARDUINO_AVR_LEONARDO)
  Serial.begin(115200);
  while (!Serial.available());
#endif
  // Power Conservation
  adc_disable(); // ADC uses ~320uA, disable it
  set_sleep_mode(SLEEP_MODE_PWR_DOWN); // default sleep mode to power down (see sleep_mode vs sleep_cpu)

  if (!firstRun()) { // on first run set some defaults to eeprom.
    loadSettings(); // if not first run, load the settings from eeprom to local variable
  }

  IRLremote.begin(IR_PIN); // begin infrared handling
  pinMode(RED_PIN, OUTPUT); // set red pin to output
  pinMode(GREEN_PIN, OUTPUT); // set green pin to output
  pinMode(BLUE_PIN, OUTPUT); // set blue pin to output
  FastLED.setCorrection(Typical8mmPixel); // compensate colours for led type
  colorBars();
}

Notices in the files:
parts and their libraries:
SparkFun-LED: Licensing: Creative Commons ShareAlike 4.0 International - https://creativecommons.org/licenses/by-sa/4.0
